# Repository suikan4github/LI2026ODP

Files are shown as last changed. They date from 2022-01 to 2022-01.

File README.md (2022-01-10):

# LI2026ODP
Over Drive Processor replacement for the SHARP LI2026A single chip calculator

# Description
The LI2026ODP is an over drive replacement of the SHARP LI2026A "calculator-on-a-chip" LSI.

Without any additional circuit board modification, LI2026ODP allow you to control the all keys and all segments of VFD. You can find a firmware at the [rpn2026 project](https://github.com/suikan4github/rpn2026).

The on board STM32G0B1KET6 micro computer 
has enough speed and memory to run a complex
firmware of a pocket calculator.

In addition to the design, followings are provided in this repository :
- [Schematic diagram](doc/LI2026ODP.pdf). 
- [BOM](doc/LI2026ODP.csv)

# Photos

# Requirement
This PCB is designed with :
- KiCAD 5.1.12

# Usage
To use LI2026ODP, simply replace the original LI2026A with the ODP board. Any other modification of the circuit board is not required. 

The SWD and UART port are provided to program and debug the on board microprocessor in the J2 port :

Pin | Description
----|-------------
1   | SWCLK
2   | GND
2   | SWDIO
3   | NRST
4   | LPUART2 TX

# License
This PCB design is distributed by CC0. See [LICENSE](LICENSE) file.

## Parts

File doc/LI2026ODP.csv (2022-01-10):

Source | /home/takemasa/git/LI2026ODP/LI2026ODP.sch
Kicad Rev | Eeschema 5.1.12-84ad8e8a86~92~ubuntu20.04.1
Generated Date | 2022/Jan/10 06:28’27” JST
Title | LI2026ODP
Company | Not Set
Revision | 1.0.0
Date Issue | 2022-01-08
Reference | Value | Library | Library Ref | Comment
U1 | LM2936MM-3.3 | LM2936MM | LM2936MM-3.3 | TSSOP 8
U3 | max6921aui+ | MAX6921AUI | max6921aui | TSSOP28
U2 | STM32G0B1KET6 | STM32G0B1KET6 | STM32G0B1KET6 | LQFP32
J1 | 9-1437539-2 | DIP28 | 9-1437539-2 | Pin Header 14*2
J2 | Conn_01x05_Male | Connector | Conn_01x05_Male
D1 | D | Device | D | Schottky 50V. 1608M
D2 | D | Device | D | Schottky 50V. 1608M
D3 | D | Device | D | Schottky 50V. 1608M
D4 | D | Device | D | Schottky 50V. 1608M
D5 | D | Device | D | Schottky 50V. 1608M
D6 | D | Device | D | Schottky 50V. 1608M
D7 | D | Device | D | Schottky 50V. 1608M
D8 | D | Device | D | Schottky 50V. 1608M
D9 | D | Device | D | Schottky 50V. 1608M
R1 | 15k | Device | R | 1608M
R2 | 15k | Device | R | 1608M
R3 | 15k | Device | R | 1608M
R4 | 15k | Device | R | 1608M
R5 | 15k | Device | R | 1608M
R6 | 15k | Device | R | 1608M
R7 | 15k | Device | R | 1608M
R8 | 15k | Device | R | 1608M
R9 | 15k | Device | R | 1608M
R14 | 27k | Device | R | 1608M
R15 | 3.3k | Device | R | 1608M
R12 | 27k | Device | R | 1608M
R13 | 3.3k | Device | R | 1608M
R10 | 27k | Device | R | 1608M
R11 | 3.3k | Device | R | 1608M
C1 | 22uF | Device | CP | Tantar 6V 2012M | TLJN226M010R3800 :CAP TANT 22UF 20% 10V
C2 | 0.1u | Device | C | Ceramic 1608M
C3 | 0.1u | Device | C | Ceramic 1608M
C4 | 0.1u | Device | C | Ceramic 1608M
C5 | 0.1u | Device | C | Ceramic 1608M

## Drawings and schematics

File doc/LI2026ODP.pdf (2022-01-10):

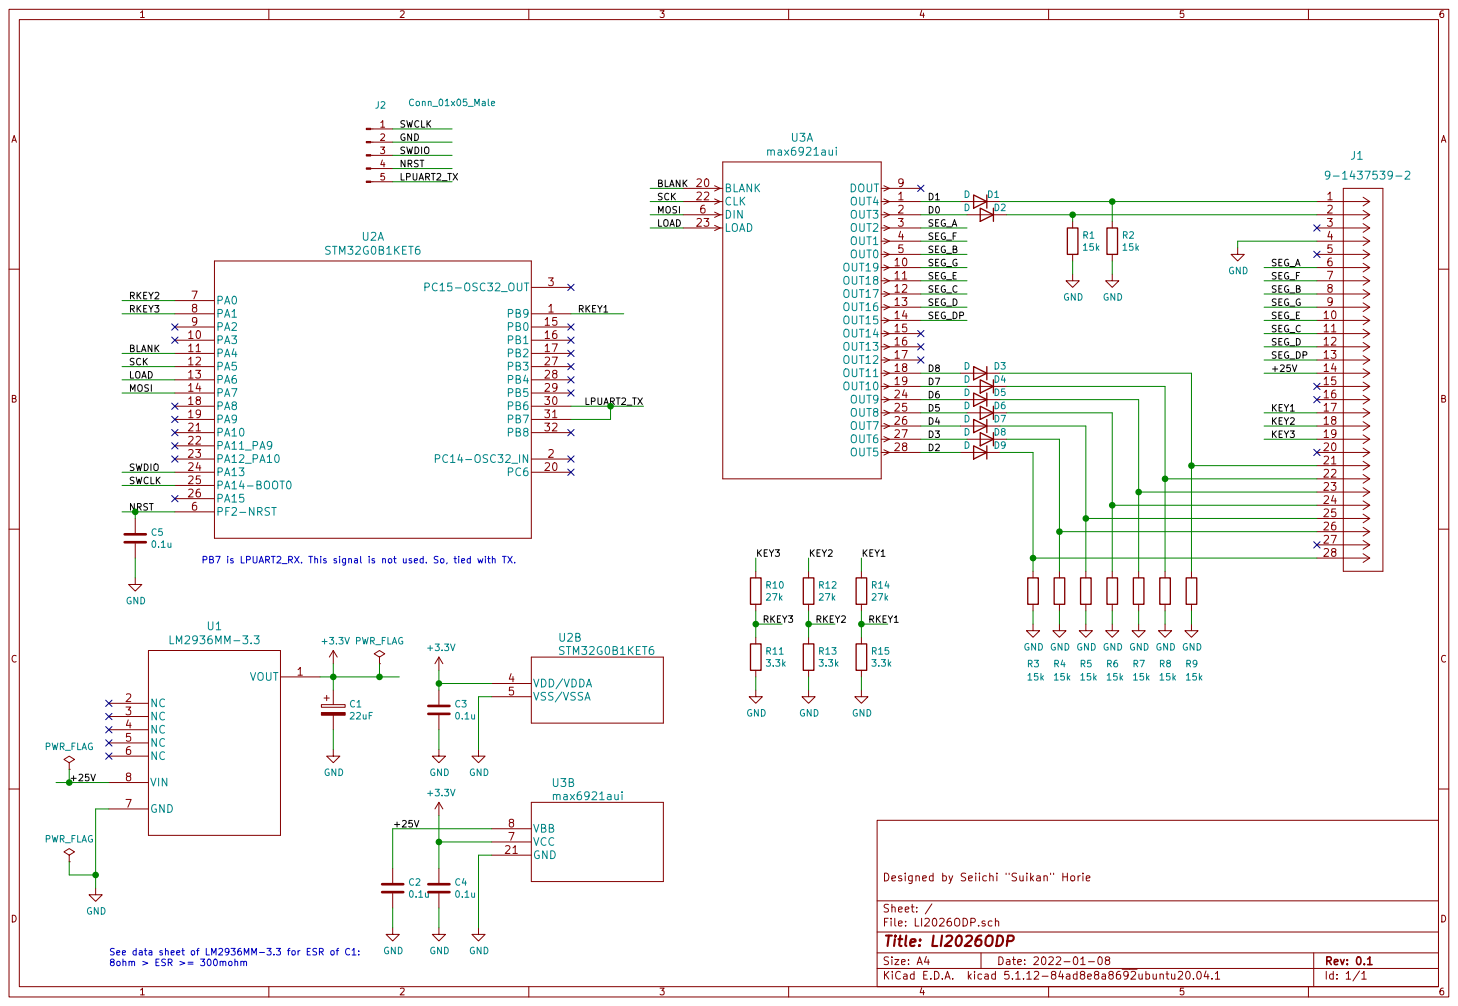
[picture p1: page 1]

PB7 is LPUART2_RX. This signal is not used. So, tied with TX. See data sheet of LM2936MM-3.3 for ESR of C1: 8ohm > ESR >= 300mohm

15k GND GND GND GND GND GND GND

File: LI2026ODP.sch Sheet: / Designed by Seiichi "Suikan" Horie

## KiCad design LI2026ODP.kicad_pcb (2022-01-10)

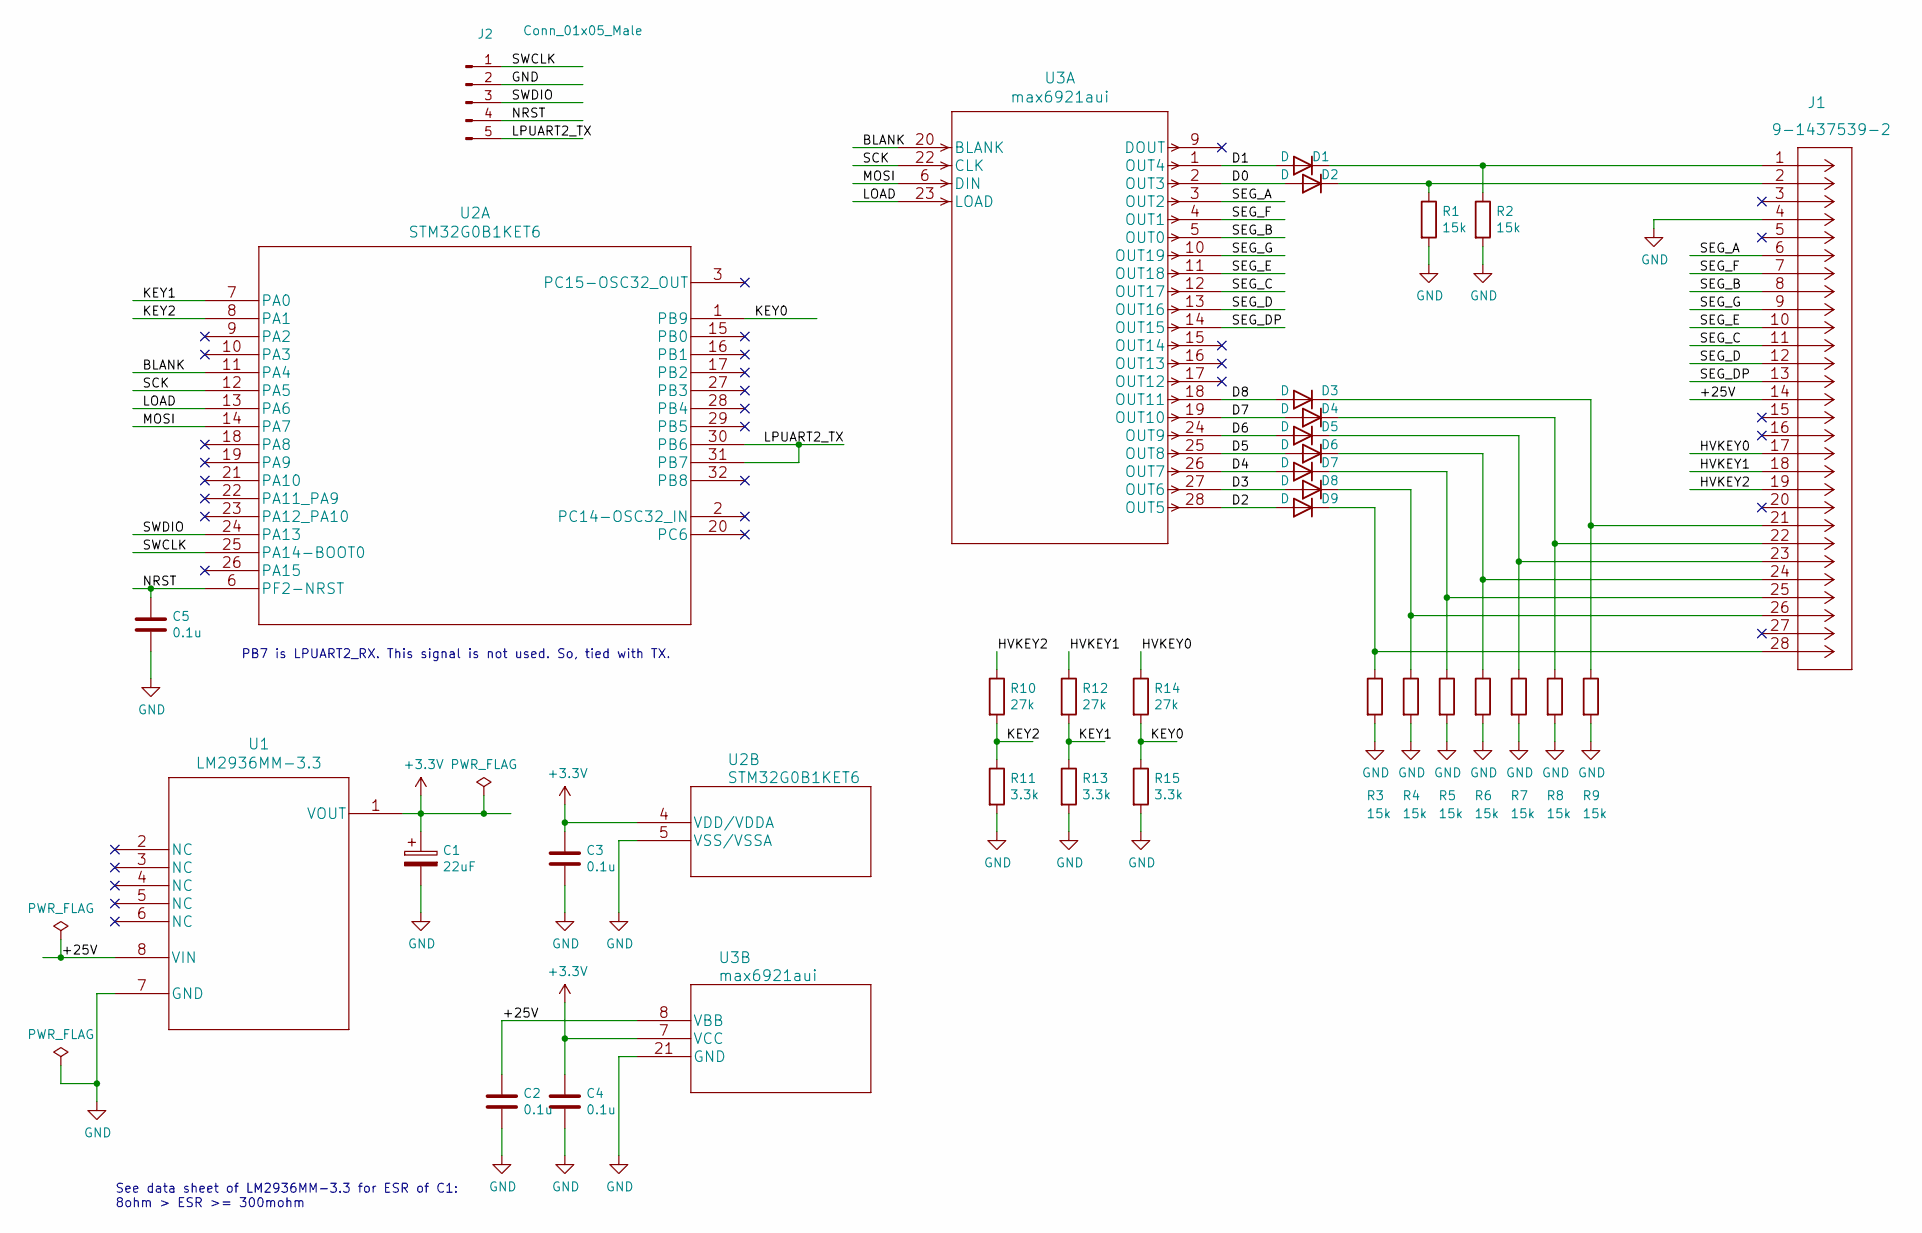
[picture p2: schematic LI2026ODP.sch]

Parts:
C1: 22uF; CP_EIA-3216-10_Kemet-I_Pad1.58x1.35mm_HandSolder
C2, C3, C4, C5: 0.1u; C_0603_1608Metric_Pad1.08x0.95mm_HandSolder
D1, D2, D3, D4, D5, D6, D7, D8, D9: D; D_0603_1608Metric_Pad1.05x0.95mm_HandSolder
J1: 9-1437539-2
J2: Conn_01x05_Male; PinHeader_1x05_P2.54mm_Vertical
R1, R2, R3, R4, R5, R6, R7, R8, R9: 15k; R_0603_1608Metric_Pad0.98x0.95mm_HandSolder
R10, R12, R14: 27k; R_0603_1608Metric_Pad0.98x0.95mm_HandSolder
R11, R13, R15: 3.3k; R_0603_1608Metric_Pad0.98x0.95mm_HandSolder
U1: LM2936MM-3.3
U2: STM32G0B1KET6
U3: max6921aui

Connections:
+3V3: C1.1, C3.1, C4.1, U1.1 (VOUT), U2.4 (VDD/VDDA), U3.7 (VCC)
/+25V: C2.1, J1.14, U1.8 (VIN), U3.8 (VBB)
/BLANK: U2.11 (PA4), U3.20 (BLANK)
/D0: D2.2 (A), U3.2 (OUT3)
/D1: D1.2 (A), U3.1 (OUT4)
/D2: D9.2 (A), U3.28 (OUT5)
/D3: D8.2 (A), U3.27 (OUT6)
/D4: D7.2 (A), U3.26 (OUT7)
/D5: D6.2 (A), U3.25 (OUT8)
/D6: D5.2 (A), U3.24 (OUT9)
/D7: D4.2 (A), U3.19 (OUT10)
/D8: D3.2 (A), U3.18 (OUT11)
/HVKEY0: J1.17, R14.1
/HVKEY1: J1.18, R12.1
/HVKEY2: J1.19, R10.1
/KEY0: R14.2, R15.1, U2.1 (PB9)
/KEY1: R12.2, R13.1, U2.7 (PA0)
/KEY2: R10.2, R11.1, U2.8 (PA1)
/LOAD: U2.13 (PA6), U3.23 (LOAD)
/LPUART2_TX: J2.5, U2.30 (PB6), U2.31 (PB7)
/MOSI: U2.14 (PA7), U3.6 (DIN)
/NRST: C5.1, J2.4, U2.6 (PF2-NRST)
/SCK: U2.12 (PA5), U3.22 (CLK)
/SEG_A: J1.6, U3.3 (OUT2)
/SEG_B: J1.8, U3.5 (OUT0)
/SEG_C: J1.11, U3.12 (OUT17)
/SEG_D: J1.12, U3.13 (OUT16)
/SEG_DP: J1.13, U3.14 (OUT15)
/SEG_E: J1.10, U3.11 (OUT18)
/SEG_F: J1.7, U3.4 (OUT1)
/SEG_G: J1.9, U3.10 (OUT19)
/SWCLK: J2.1, U2.25 (PA14-BOOT0)
/SWDIO: J2.3, U2.24 (PA13)
GND: C1.2, C2.2, C3.2, C4.2, C5.2, J1.4, J2.2, R1.2, R2.2, R3.2, R4.2, R5.2, R6.2, R7.2, R8.2, R9.2, R11.2, R13.2, R15.2, U1.7 (GND), U2.5 (VSS/VSSA), U3.21 (GND)
unnamed: D1.1 (K), J1.1, R2.1
unnamed: D2.1 (K), J1.2, R1.1
unnamed: D3.1 (K), J1.21, R9.1
unnamed: D4.1 (K), J1.22, R8.1
unnamed: D5.1 (K), J1.23, R7.1
unnamed: D6.1 (K), J1.24, R6.1
unnamed: D7.1 (K), J1.25, R5.1
unnamed: D8.1 (K), J1.26, R4.1
unnamed: D9.1 (K), J1.28, R3.1

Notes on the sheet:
PB7 is LPUART2_RX. This signal is not used. So, tied with TX.
See data sheet of LM2936MM-3.3 for ESR of C1: 8ohm > ESR >= 300mohm

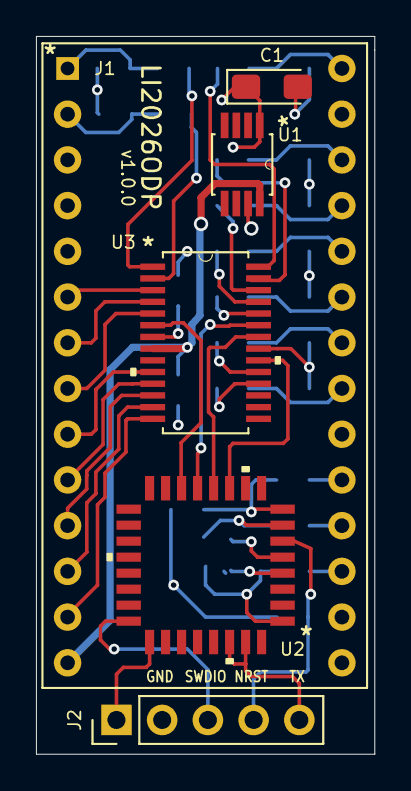
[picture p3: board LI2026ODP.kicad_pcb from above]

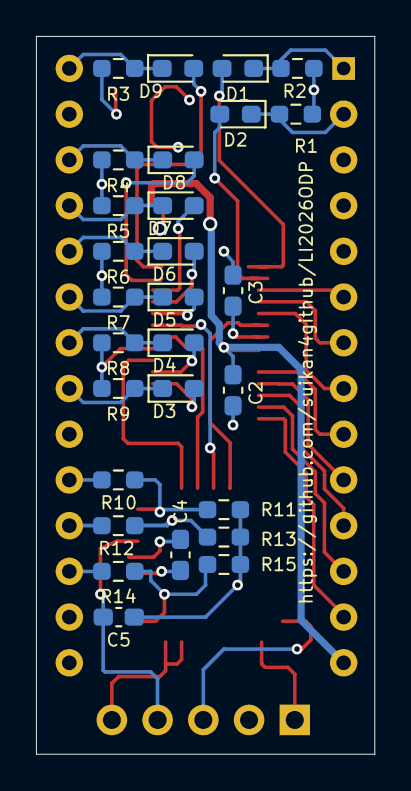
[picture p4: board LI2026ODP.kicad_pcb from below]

Board: 4 copper layers, 18.8 x 39.9 mm, 34 parts (28 on the bottom side), 43 nets.

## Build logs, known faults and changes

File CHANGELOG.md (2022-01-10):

# Change Log
All notable changes to this project will be documented in this file.

The format is based on [Keep a Changelog](http://keepachangelog.com/)
and this project adheres to [Semantic Versioning](http://semver.org/).

## [Unreleased] - YYYY-MM-DD
### Added
### Changed
### Fixed

## [1.0.0] - YYYY-MM-DD
### Added
### Changed
### Fixed

[Unreleased]: https://github.com/suikan4github/template_application/compare/v1.0.0...develop
[1.0.0]: https://github.com/suikan4github/template_application/compare/v0.0.0...v1.0.0

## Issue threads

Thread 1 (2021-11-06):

Images storage.

suikan4github, 2021-11-06:
This issue is as the placeholder of the wiki image.

Segment image :
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

Pin1, Digit 1 :
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

Pin13, Segment dp :
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

Pin 27, -9V :
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

Pin 15, -7V :
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

Pin 4, -27V :
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

Heater :
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

Closed 2022-01-10.

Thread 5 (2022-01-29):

Modify the U2 Footprint.

suikan4github, 2022-01-29:
The footprint is mismatched.

The current footprint from Ultra Librarian has a 0.9mm pitch, while the STM32G0B1KET6 has a 0.8mm pitch.

Must substitute with the right one.

suikan4github, 2022-01-30:
Done.

Closed 2022-01-30.

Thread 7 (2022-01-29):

Refine the bypass capacitor  allocation

suikan4github, 2022-01-29:
C3 and C4 should be swapped.

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

suikan4github, 2022-01-29:
Swapped C3 and C4 in the schematics. The PCB layout is kept.

suikan4github, 2022-01-29:
Done.

Closed 2022-01-29.

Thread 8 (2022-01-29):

Add capacitor for 25v line

suikan4github, 2022-01-29:
0.1uF is needed to stabilize the voltage regulator.

This capacitor must be closer to the voltage regulator.

suikan4github, 2022-01-30:
Done.

Closed 2022-01-30.

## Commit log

2022-01-07 Starting layout.
    [LI2026ODP.kicad_pcb, LI2026ODP.sch]
2022-01-08 All parts connected.
    Waiting for the routing.
    [LI2026ODP.kicad_pcb, LI2026ODP.sch]
2022-01-08 Change SMD from 1005M to 1608M
    [LI2026ODP.kicad_pcb, LI2026ODP.sch]
2022-01-08 layout finished.
    [LI2026ODP.kicad_pcb]
2022-01-08 Fix the BLANK bug and change layout
    - BLANK was incorrectly tied with 3.3v
    - Make layer 3 as +3.3v
    - Make 25v line as 0.4mm
    - Change RKEY1,2,3 pins for the simple layout.
    [LI2026ODP.kicad_pcb, LI2026ODP.sch]
2022-01-09 Change voltage regulator
    from 3.0 to 3.3v
    [LI2026ODP.kicad_pcb, LI2026ODP.sch]
2022-01-09 Clean up the wire in the power layer.
    [LI2026ODP.kicad_pcb, LI2026ODP.sch]
2022-01-09 Schematics and Layouts refreshed.
    Unsed comments are deleted.
    [LI2026ODP.kicad_pcb, LI2026ODP.sch]
2022-01-09 The bypass capacitor layout of the microprocessor is optimized.
    [LI2026ODP.kicad_pcb]
2022-01-09 Update C1 from 1608 to 2012
    [LI2026ODP.kicad_pcb, LI2026ODP.sch]
2022-01-09 Move LSI's to left
    To align them ceter of the board.
    [LI2026ODP.kicad_pcb]
2022-01-09 Add capacitor to NRST for noise protection.
    [LI2026ODP.kicad_pcb, LI2026ODP.sch]
2022-01-09 Add BOM file
    [LI2026ODP.csv]
2022-01-09 Change BLANK control of MAX6921
    from the hardwired to the software control.
    [LI2026ODP.kicad_pcb, LI2026ODP.sch]
2022-01-09 Add README comment
    Also add PDF schematics.
    [LI2026ODP.csv, LI2026ODP.sch]
2022-01-10 Add gerber file output
    [LI2026ODP-B_Cu.gbl, LI2026ODP-B_Mask.gbs, LI2026ODP-B_Paste.gbp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]
2022-01-10 Rename the key matrix signals.
    Aligned with the program ( zero origine ).
    [LI2026ODP-B_Cu.gbl, LI2026ODP-B_Mask.gbs, LI2026ODP-B_Paste.gbp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]
2022-01-10 Place order to Fusion PCB
    [LI2026ODP-B_Cu.gbl, LI2026ODP-B_Mask.gbs, LI2026ODP-B_Paste.gbp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]

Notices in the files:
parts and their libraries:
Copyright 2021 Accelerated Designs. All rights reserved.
